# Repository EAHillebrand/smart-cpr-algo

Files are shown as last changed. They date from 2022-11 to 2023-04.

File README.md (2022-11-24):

# smart-cpr-algo
Model for smart CPR training mannequin

Developer Names: Anna, Anna, Eric, & Janek

Date of project start: Sept 8th, 2022

This project is a CPR training mannequin that provides live feedback to the learner. 

The folders and files for this project are as follows:
docs - Documentation for the project 
refs - Reference material used for the project, including papers 
src - Source code test - Test cases etc

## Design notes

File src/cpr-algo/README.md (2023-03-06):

# Simulink Model Details

Download cpr_vX.zip

Open and run the init_top_level.m
 -->Can choose the data loaded in init by which line is uncommented

Then open top_level_algo.slx (not .slxc)

Under simulation tab change run time to appropriate value

Then run from simulation tab

## Subsystem Notes

 ### Hardware Hiding:
 - Converts raw ADC value to distance in mm, uses low pass filter to limit bit switching

 ### Direction:
 - Determines the direction of distance (pos, zero, or neg)

 ### MinMax:
 - Identifies Local max and Min displaceent during compression

 ### Compression Detection:
 - Identifies a complete compression, counts number of compressions, records duration of compression in seconds

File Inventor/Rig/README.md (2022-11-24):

# Testing setup 

Used for collecting potentiometer data
Top level assembly is test

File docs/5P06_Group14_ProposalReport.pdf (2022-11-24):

### McMaster University

### IBEHS 5P06

# CPR Smart Mannequin Proposal Report

### October 21, 2022

Submitted by:

Group 14
Name | Email | Student ID
Anna Green | greena18@mcmaster.ca | 400117023
Anna Lopatukhin | lopatuka@mcmaster.ca | 400116519
Eric Hillebrand | hillebre@mcmaster.ca | 400143468
Janek Wolos | wolosj@mcmaster.ca | 400131936

### Table of Contents

Background Research | 3
Design Criteria | 5
Plan for Design Process | 6
Impact | 7
References | 8
Appendix A | 11
Appendix B | 12
Appendix C | 13
Anna Green | Eric Hillebrand
Anna Lopatukhin | Janek Wolos

### Background Research

CPR Overview: Cardiopulmonary resuscitation (CPR) is an emergency procedure administered during cardiac arrest wherein chest compressions are performed to replace the pumping of the heart and allow blood to keep flowing through the body. It is reported that about 9 in 10 people who experience cardiac arrest outside a hospital die [1]. If CPR is administered within the first few minutes of cardiac arrest, the chance of survival can double or triple [1]. There are various CPR certification courses available, but you do not require a certification or formal training to administer CPR [1]. There are two commonly known versions of CPR, conventional CPR, which uses chest compressions and mouth-to-mouth breathing, and compression-only CPR, which is simply conventional CPR without mouth-to-mouth breaths [2]. This background research focuses on adult CPR only. The Canadian Red Cross training services have outlined steps for administering conventional CPR to adults, shown in Figure 1A in Appendix A. The official CPR guidelines from the Heart and Stroke foundation outline that compressions must be at least 5 cm in depth with complete chest recoil, be performed at a rate of 100-120 compressions/min, have minimal interruptions, and that the compressor should use a 30:2 compression-ventilation ratio, and switch out with another compressor every 2 minutes [3]. The hands should be centered on the chest, with shoulders directly over the hands and elbows locked [4].

Smart CPR Mannequins: Smart CPR aids provide users with meaningful real-time feedback that improves CPR performance. The devices provide information to instructors so they can be effective teachers and precise evaluators. Smart training aids are available with a wide range of features. A number of smart mannequins were investigated and a summary table can be found in Table 1 of Appendix B. The features focus on relaying critical information, such as depth and rate of compressions, back to the user through audio and visual cues. The smart devices can relay the information to a central display to give instructors statistics and infographics on the class. The devices’ accurate, live feedback helps improve CPR training outcomes and retention [3]. An example of using smart mannequins was shown in a study where elderly participants learned how to perform CPR by watching a 30-min self-instructed video program while using an inflatable smart mannequin [5]. The CPR quality equaled a 4-hour professional class. After the training sessions, a smart mannequin was used to quantify the participants’ CPR proficiency [5]. In trained professionals, live feedback from smart mannequins during CPR training improved performance and received high ratings for usefulness and ease of use [6].

Regulations for CPR Mannequins: As the smart CPR mannequin is used for training, and not for treatment or health monitoring, it is not classified as a medical device and needs no regulatory approval process. Instead, the regulations are defined by various first-aid training bodies and foundations, most popular being the American Heart Association (AHA) and their 2020 Guidelines [7]. The guidelines contain several recommendations and standards for the design that should be met in a successful training device, including the types of feedback given and the evaluation methods. While it is up to individual foundations to decide whether they want to use a particular mannequin for training, most base their decision on meeting the AHA Guidelines [8].

Anna Green | Eric Hillebrand

Patents
Patents of current designs were studied to better understand our market environment. The solutions found can be broken down into three main areas: regular mannequins, smart mannequins, and CPR feedback devices.

Regular Mannequins: These patents provide descriptions of the mechanical design and feedback system, such as spring design, simulating chest compressions and airways, and the mannequin anatomical structure [9], [10], [11]. They provide information on durability, portability, and manufacturing solutions [9], [10], [11]. One of the patents uses a fluid to provide a damping effect, stepping away from the linear spring method used in other cases, which research has shown to be more accurate of a real chest during compression [9].

Smart Mannequins: In addition to the mechanical design trying to mimic a realistic torso, this patent contains a sensor housing fitted with a force sensor and an acceleration sensor [12]. The patent goes in-depth about the types and layout of the sensors, explaining the idea behind having separate sensors working together as a fail-proof mechanism [12].

CPR Feedback Devices: These patents are for monitoring devices that use sensors to provide feedback on the quality of the CPR given during an emergency [13], [14]. One relies on pressure pads on the chest and back of the patient and uses the difference in the amplitudes and frequency collected to calculate compression and rate [14]. The second device uses an ultrasonic wave transmitter on the chest and a receiver on the back of the victim. The time of flight between the transmitter and receiver is used to calculate compression depth and the frequency [13]. As these are to be used on humans, it is less applicable to our training use case, however we could take inspiration from the solutions for the sensor setup and type of data collected.

### Problem Statement and Needs Identification

Problem Statement: Lack of effective CPR education of laypersons in developing countries is currently hindering the administration of lifesaving treatment for out-of-hospital cardiac arrests (OHCA), which occurs with an annual incidence of 350,000 in the United States alone and has a mortality rate of approximately 90% [15]. A method to effectively and easily teach CPR to laypersons of various backgrounds and education is needed, ensuring that trainees can perform quality CPR in an emergency and retain the information and skill set for sufficient time.

Client Needs: The client requires a means of delivering effective CPR training to laypersons in developing countries. The client has allowed for an open-ended method of accomplishing this goal, giving examples such as a smart CPR mannequin, or a CPR training program. Although the client seemed more focused on a smart CPR mannequin, we intend to quell this bias as much as possible in our brainstorming process, as the problem statement outlines only that a CPR training solution be implemented. CPR training relies on providing the learner with the necessary information and skillset, and ensuring retention of the skill to later perform in an emergency setting. This requires professional instruction and repetition of good technique on a realistic subject. No matter the physical manifestation of the solution, it must be able to measure and give real time feedback to both the student and the instructor pertaining to the quality of chest compressions. Quality of chest compressions is broken down into quality of compression rate,
Anna Green | Eric Hillebrand

depth, recoil, chest compression fraction, and hand position. The client has specified that ventilation is not a requirement for the CPR training they wish to give. Further research to justify this choice shows that compression-only CPR is easier for a layperson to perform, and that it results in similar survival rates for adult cardiac arrests of cardiac etiology compared to CPR with rescue breaths [16]. The client also requires that the quality-of-compression data be available to provide remote certification of CPR competence. The structure of CPR lessons is assumed to remain consistent with instruction followed by practicing the skill and receiving feedback. The client specified that electronic components need to have a shelf life greater than 2 years, so that the battery and components must last through regular use and possible charging. The aid must also be convenient to transport overseas, and must use universal conventions to be easily used in different countries.

Uncertainties and Challenges: The lack of robust and routine data collection surrounding OHCA in developing countries makes it difficult to put the problem statement and client needs into quantitative terms. The motivation behind this project was derived from lived experience and probabilistic evidence sourced by the client related to CPR training in developing countries. While there are studies that focus on OHCA in developing countries, those studies are, again, founded on limited statistical evidence. Furthermore, the client has listed many countries in which they have connections for a CPR training program to be started, but they have not decided which specific country they would like to target. This might present some issues when assessing feasibility of solutions in different countries, and designing for specific languages and cultures of learning. This could mean that we create our own scope and choose a specific country to target ourselves.

### Design Criteria

The following design criteria are guided by minimum features of adult CPR mannequins established by the American Red Cross First Aid CPR certification courses and professional guidelines for performing CPR from the Heart and Stroke foundation [3].

Affordability: In discussions with stakeholders involved in CPR training programs, it was identified that having a low cost product is of significant importance. The product should be more affordable compared to current existing models and ideally, be easily purchased in developing countries. This will be quantifiable, with a goal to achieve a cost less than $172, which is the price for a basic feedback-capable mannequin available for sale [17].

Portability: The product should be easily portable. Devices that are too large become difficult to transport (especially overseas) and may discourage users from purchasing the product. This will be quantifiable, with a goal to have a design less than 7lbs, which is the weight for a standard CPR mannequin [18]. The device should be usable without electrical connection during use, be easily charged and/or require batteries that are universally accessible.

Safety: The device must have minimal safety risk. This means the integrity of all mechanical and electrical components is confirmed. At a minimum, the design will be as safe as current products on the market. The device should not include materials such as latex, which may cause allergic reactions in some users.

Anna Green | Eric Hillebrand

Accessibility: Operation should be easily understood regardless of prior knowledge, experience, or language(s) spoken. The product should incorporate as many non-linguistic cues as possible, such as lights, sounds, vibrations, etc., which can be adjusted to fit the needs of the user. If linguistic cues are needed, it should aim to be able to accommodate different languages.

Durability: The product should be made of materials that increase longevity and sustainability of the device, and be able to withstand a minimum of 125 uses [19]. The material should be minimally absorbent and easily disinfected, to mitigate the transfer of communicable diseases [19]. The instructions for decontamination must be simple and distributed with the product.

Feedback System: The feedback system should incorporate real-time simulated audio, visual or sensory cues which respond accurately to the depth, compression rate, and fraction. The feedback must accurately follow professional guidelines established by the Heart and Stroke foundation [3]. These guidelines identify a minimum depth of 5 cm, a compression rate of 100-120/ min, complete chest recoil, and minimal interruptions in compressions [3]. A successful feedback system will identify when the user is matching guidelines, nearing the guidelines, or failing to meet the guidelines. The feedback system may ideally notify the user when compression has exceeded 2 minutes, as it is recommended the CPR provider is changed every 2 minutes [3].

Ease of Manufacturing: A desirable design should be easily manufacturable. This will likely reduce the cost and make maintenance/repairs more accessible. Easily manufacturable designs will be identified by their use of standard parts, easily replaceable components, and the use of standard practices in manufacturing.

Sensor and Measurements: The sensor system of the design should collect reliable, robust and consistent data as it will be used downstream in providing the feedback to the trainee. As the measurements will be used as the foundation for the rest of the system, the data flow needs to be consistent under all conditions and pass a variety of stringent hazard analyses.

Design Criteria Challenges
The main challenges that will have to be addressed for this design will revolve around finding a good middle ground amongst the criteria defined above. When taken to the extremes, some of the design requirements are conflicting to one another, for example, extremely high quality sensors will not be the most affordable. Finding the optimal point to maximize each of them will be a significant obstacle, and will take planning and several iterations to get right.

### Plan for Design Process

The project plan, deliverables, and detailed timeline is found in the Gantt Chart in Appendix C.

Semester 1: The team will participate in background research, design process planning, and problem identification and analysis. In October/November, members will generate initial design ideas and then select a final design after a design review. In early December, the team will order the required parts and/or begin fabrication of components.

Anna Green | Eric Hillebrand

Semester 2: The team will build, test, and refine the device. In January, the team will build the first prototype. In early February, testing will begin. In late February, a second prototype will be built with further testing. The rest of the term will be overflow in case challenges arise.

Potential Challenges: To build in semester 2, the preliminary design must be completed by mid-December to allow time for parts procurement and fabrication. If the majority of parts are to be fabricated, fabrication may be pushed to mid/late January. However, parts identification will start in mid November, so if it is identified that the majority of parts need to be fabricated, the Mechanical Sub-Team will adjust the schedule accordingly.

Fabrication Planning and Budget Considerations: All members will keep in mind the budget of $1000. All members will receive second-floor machine shop and hatch bay training for fabrication purposes.

### Impact

Even in the U.S., the mortality rate from OHCA is still 90% on some 350,000 events each year. In developing countries, the belief that CPR can only be performed by medical professionals in hospitals is strongly held. It is evident that effective layperson CPR training would have a great benefit to unlearning this belief and saving lives around the world. In a scoping review performed by Thibodeau et al. pertaining to OHCA in Africa, several papers identified cardiovascular disease (CVD) as an underlying cause of OHCA, and discussed how the incidence of CVD is expected to double in Africa [20]. We can proactively prepare the public to deal with this impending increase in OHCA through the implementation of CPR training. The development of a feedback-based CPR training tool in this project will have a strong impact in this respect, as shown by studies that discuss the benefits of CPR training with feedback, compared to no feedback. One study found that people trained with just one minute of real-time visual feedback scored 10.8% higher than the people with no feedback in overall CPR score (which accounted for compression depth and rate, chest recoil, hand position) [21]. Another study had one group of participants watching an instructional video while practicing CPR on a mannequin, and another group receiving real-time computer-voice feedback on the quality of their CPR. The non-feedback group only improved from 5% to 8% of participants successfully meeting all the CPR criteria, whereas the feedback group improved from 4% to 19% [22]. Not only will this project have an impact on people requiring life support from witnesses to OHCA, but it will also impact CPR instructors. The American Heart Association discusses the difficulty of detecting inadequate CPR performance in traditional instruction practices, which makes it challenging to fine tune the feedback they give. They believe that implementing a more technologically advanced, feedback-based CPR training solution would help tackle this problem [23].

Anna Green | Eric Hillebrand

### References

[1] “Three things you may not know about CPR,” Centers for Disease Control and Prevention, 22-Oct-2021. [Online]. Available: https://www.cdc.gov/heartdisease/cpr.htm. [Accessed: 20-Oct-2022].
[2] “What is CPR,” cpr.heart.org. [Online]. Available: https://cpr.heart.org/en/resources/what-is-cpr. [Accessed: 20-Oct-2022].
[3] “2020 Guidelines for CPR & ECC,” Heart & stroke training portal. [Online]. Available: https://cpr.heartandstroke.ca/s/article/2020-Guidelines?language=en_US. [Accessed: 20-Oct-2022].
[4] “CPR steps: Perform CPR,” Red Cross. [Online]. Available: https://www.redcross.org/take-a-class/cpr/performing-cpr/cpr-steps. [Accessed: 20-Oct-2022].
[5] B. Lynch, E. L. Einspruch, G. Nichol, L. B. Becker, T. P. Aufderheide, and A. Idris, “Effectiveness of a 30-min CPR self-instruction program for Lay Responders: A controlled randomized study,” Resuscitation, vol. 67, no. 1, pp. 31–43, Oct. 2005.
[6] J. R. Smart, K. Kranz, F. Carmona, T. W. Lindner, and A. Newton, “Does real-time objective feedback and competition improve performance and quality in manikin CPR training – a prospective observational study from several European EMS,” Scandinavian Journal of Trauma, Resuscitation and Emergency Medicine, vol. 23, no. 1, 2015.
[7] A. Cheng, D. J. Magid, M. Auerbach, F. Bhanji, B. L. Bigham, A. L. Blewer, K. N. Dainty, E. Diederich, Y. Lin, M. Leary, M. Mahgoub, M. E. Mancini, K. Navarro, and A. Donoghue, “Part 6: Resuscitation education science: 2020 American Heart Association guidelines for Cardiopulmonary Resuscitation and emergency cardiovascular care,” Circulation, vol. 142, no. 16_suppl_2, 2020.
[8] “Use of Feedback Devices in Resuscitation Training Courses Policy,” Heart & stroke training portal. [Online]. Available: https://cpr.heartandstroke.ca/s/article/Use-of-Feedback-Devices-in-Resuscitation-Training-Courses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. [Accessed: 20-Oct-2022].
[9] J. Nysaether and I. Rafoss, “Chest simulator,” US20070264621A1, 15-Nov-2007.
[10] R. Brault, D. Croteau, and J. Vinden, “CPR manikin,” US4984987A, 15-Jan-1991.
[11] J. Lehman, “Training manikan,” US5628633A, 13-May-1997.
Anna Green | Eric Hillebrand

[12] Y. Kwon, S. Park, S. Lee, H. Lee, “Cpr training system and method,” EP3440659B1, 1-December-2021
[13] P. Peterson, K. Olson, “CPR feedback method and apparatus,” US8600522B2, 3-December- 2013
[14] C. Centen, S. Smith, G. Browne, R. Lee, M. Wilkinson, R. Nova, “Reference sensor for cpr feedback device,” US20120083720A1, 8-Novemeber-2016
[15] “CPR Facts and stats,” cpr.heart.org. [Online]. Available: https://cpr.heart.org/en/resources/cpr-facts-and-stats. [Accessed: 20-Oct-2022].
[16] “Highlights - heart and stroke foundation of Canada,” American Heart Association. [Online]. Available:
https://www.heartandstroke.ca/-/media/pdf-files/canada/cpr-2017/ecc-highlights-of-2015-guidelines-update-for-cpr-ecclr.ashx. [Accessed: 21-Oct-2022].
[17] EMS Safety United States. [Online]. Available: https://store.osmanager4.com/emss/groups/459/1230. [Accessed: 20-Oct-2022].
[18] “Covid 19 essentials,” CPR Savers & First Aid Supply. [Online]. Available: https://cpr-savers.com/CPR-Manikin-Comparison-Chart_ep_63-1.html. [Accessed: 20-Oct-2022].
[19] “American Red Cross training manikin requirements - CPR savers.” [Online]. Available: https://cpr-savers.com/assets/images/pdf/american-red-cross-training-manikin-requireme nts.pdf. [Accessed: 20-Oct-2022].
[20] J. Thibodeau, K. Werner, L. A. Wallis, and W. Stassen, “Out-of-hospital cardiac arrest in Africa: A scoping review,” BMJ Open, vol. 12, no. 3, 2022.
[21] E. Baldi, S. Cornara, E. Contri, F. Epis, D. Fina, B. Zelaschi, C. Dossena, F. Fichtner, M. Tonani, M. Di Maggio, E. Zambaiti, and A. Somaschini, “Real-time visual feedback during training improves laypersons’ CPR quality: a randomized controlled manikin study,” CJEM, vol. 19, no. 6, pp. 480–487, 2017.
[22] N. Mpotos, L. Yde, P. Calle, E. Deschepper, M. Valcke, W. Peersman, L. Herregods, and K. Monsieurs, “Retraining basic life support skills using video, voice feedback or both: A randomised controlled trial,” Resuscitation, vol. 84, no. 1, pp. 72–77, 2013.
[23] “American Heart Association (AHA) requirement on use of feedback devices ...” [Online].
Anna Green | Eric Hillebrand

Available:https://ahainstructornetwork.americanheart.org/idc/groups/ahaecc-public/@wcm/@ecc/documents/downloadable/ucm_495639.pdf. [Accessed: 20-Oct-2022].

[24] “3 4 - Canadian Red Cross.” [Online]. Available: https://www.redcross.ca/crc/documents/fa_poster_cpr_web.pdf. [Accessed: 20-Oct-2022].
[25] “Professional adult series 2000 manikin,” PRESTAN Products. [Online]. Available: https://www.prestanproducts.com/products/cpr-training-manikins/professional-adult-series-2000-manikin/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. [Accessed: 20-Oct-2022].
[26] SmartMan, “World's best resuscitation practice,” SmartMan Emergency Resuscitation Simulation Systems. [Online]. Available: http://smartman.biz/. [Accessed: 20-Oct-2022].
[27] “Little Anne QCPR - creating Quality Lifesavers,” Laerdal Medical. [Online]. Available: https://laerdal.com/ca/products/simulation-training/resuscitation-training/little-anne-qcpr. [Accessed: 20-Oct-2022].
[28] “HAL® S315 adult airway and CPR trainer with OMNI® 2,” Gaumard Scientific. [Online]. Available: https://www.gaumard.com/s315-omni2. [Accessed: 20-Oct-2022].
Anna Green | Eric Hillebrand

### Appendix A

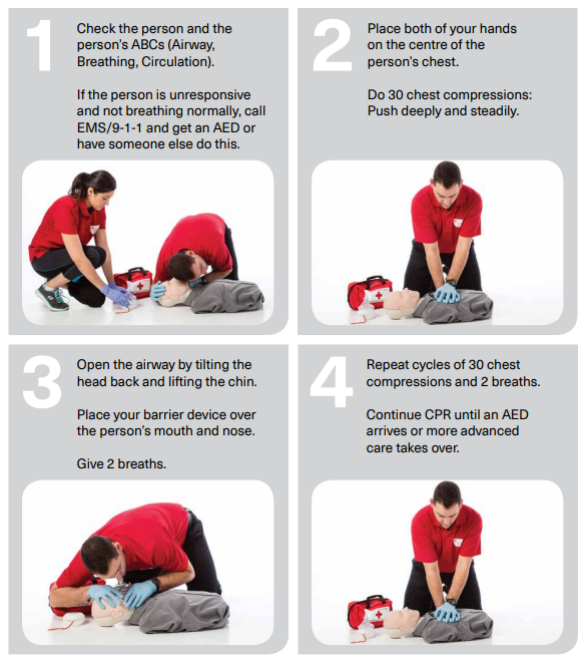
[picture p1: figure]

Figure 1A: Canadian Red Cross Conventional CPR Steps for an Adult [24]

Anna Green | Eric Hillebrand

### Appendix B

Table 1: Current Smart Mannequins on the Market and Key Features
Product Name | Company | Description | Key Features | Cost (CAD)
Professional Adult Series 2000 Manikin [25] | Prestan | Realistic adult mannequin with advanced real-time feedback Fully compliant with industry guidelines Available in different skin tones | Compression rate Depth Recoil Ventilation Hands-off time Bluetooth connection Mobile app LED feedback | 302.28
BLS CPR Pro – SM201 [26] | SmartMan | Adjustable-Real chest resistance Monitors performance and detects Mistakes | Real-time feedback Metronome External screen Compression modes | Not Available
Little Anne QCPR [27] | Laerdal | Quality CPR (QCPR) feedback technology Help instructors improve CPR training quality, classroom efficiency and learner engagement. | Real-time feedback Race competition Scoring Guidance | 310
HAL® S315 Adult Airway and CPR Trainer with OMNI® 2 [28] | Gaumard | A CPR trainer designed for teaching resuscitation skills Realistic chest cavity resistance and recoil Performance report providing averages for CPR metrics | Real-time feedback Compression depth Rate Ventilation rate Excessive ventilation Metronome Resuscitation algorithm Checklists | 2135
Anna Green | Eric Hillebrand

### Appendix C

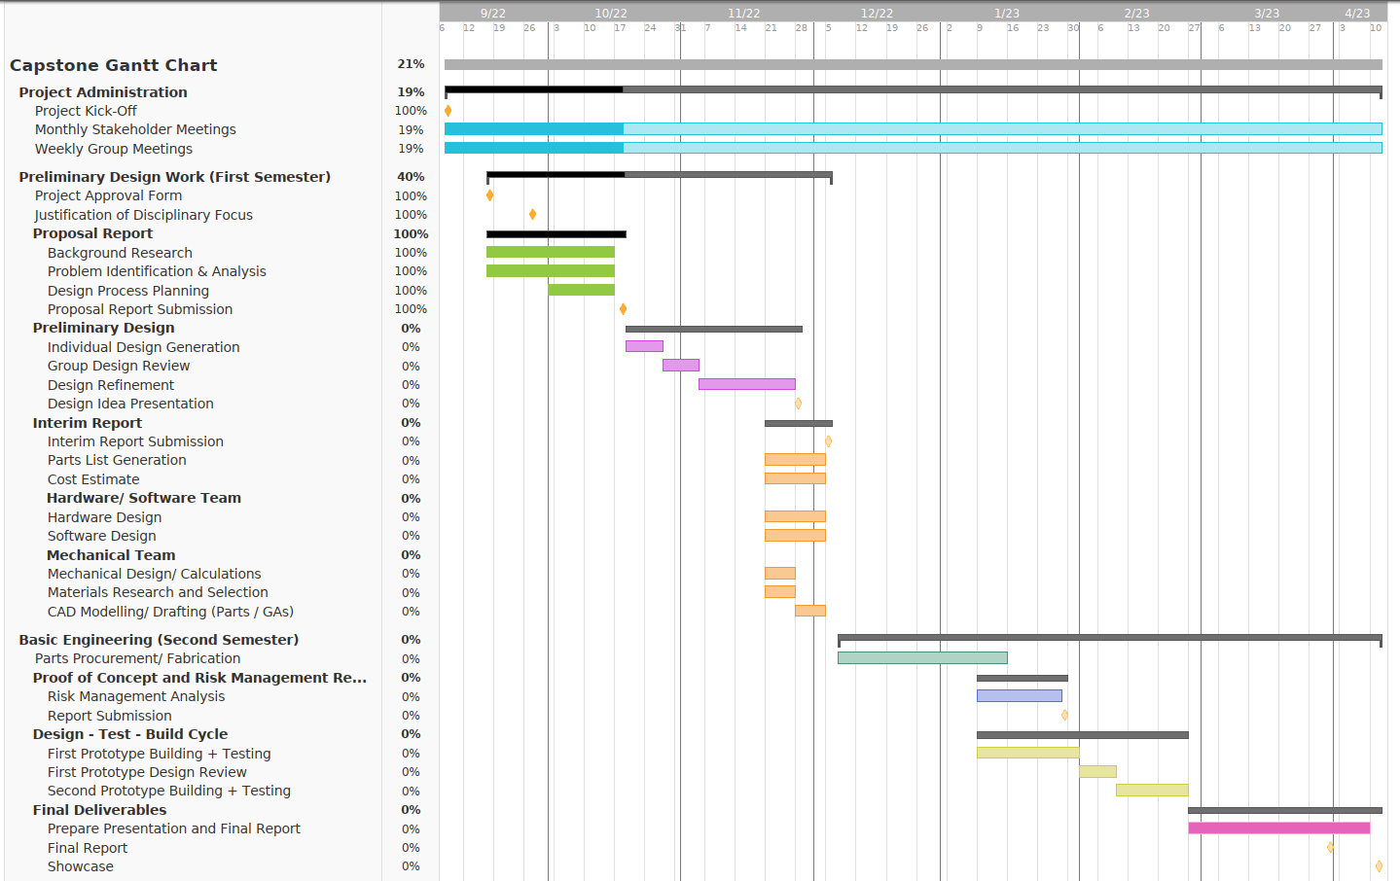
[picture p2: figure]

Figure 1C: Gantt Chart
Anna Green | Eric Hillebrand
Anna Lopatukhin | Janek Wolos

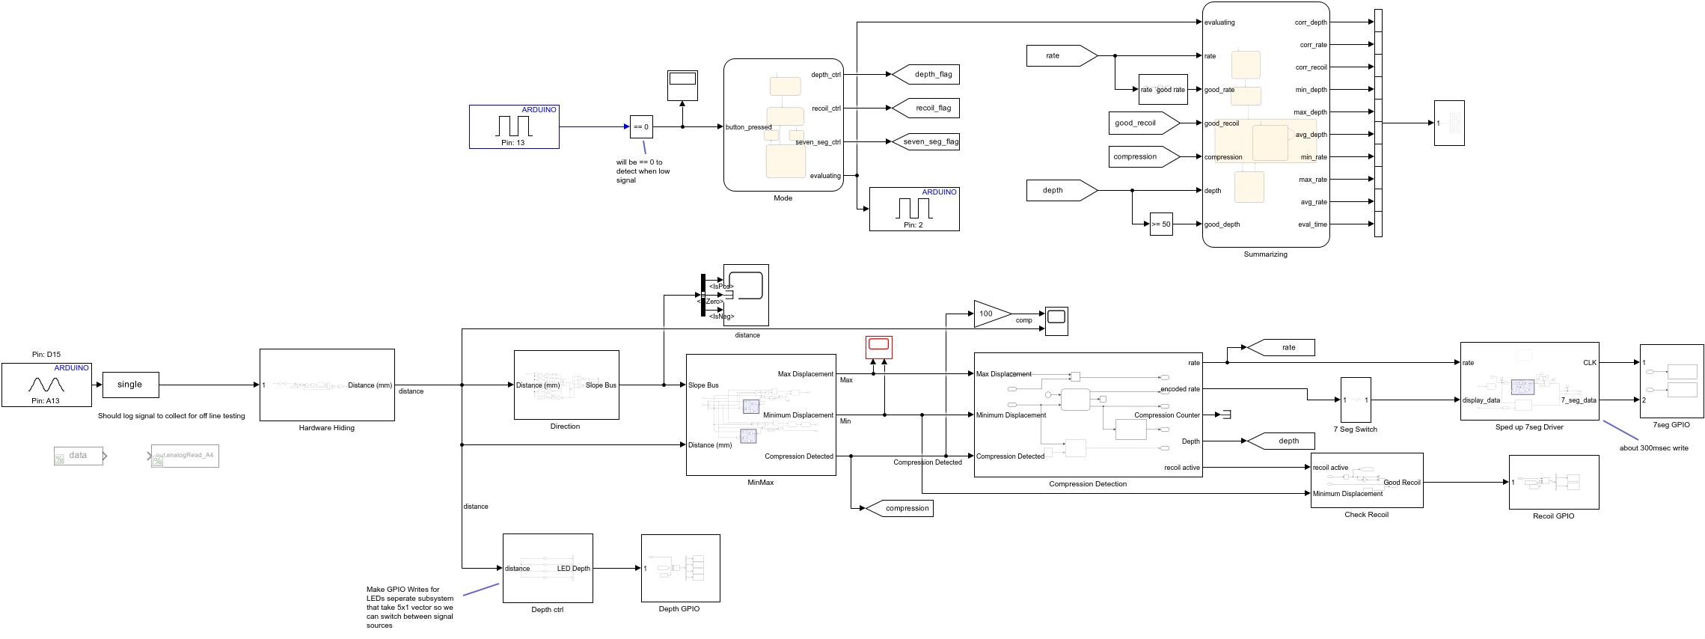
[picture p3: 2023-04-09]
src/cpr-algo/model.jpeg

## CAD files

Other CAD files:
Inventor/Rig/3D_model_PN_3540s-1-503l.ipt
Inventor/Rig/base.ipt
Inventor/Rig/bushing_loose.ipt
Inventor/Rig/bushing_tight.ipt
Inventor/Rig/gear_trial1.iam
Inventor/Rig/pinion.ipt
Inventor/Rig/pinion_gear.ipt
Inventor/Rig/pinion_gear_loose.ipt
Inventor/Rig/pinion_gear_mid.ipt
Inventor/Rig/pinion_gear_tight.ipt
Inventor/Rig/pot_stand.ipt
Inventor/Rig/push_plate.ipt
Inventor/Rig/rack.ipt
Inventor/Rig/rack_tooth.ipt
Inventor/Rig/rod.ipt
Inventor/Rig/test.iam

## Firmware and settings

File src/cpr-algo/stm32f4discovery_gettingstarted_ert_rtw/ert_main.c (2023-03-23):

/*
 * Academic License - for use in teaching, academic research, and meeting
 * course requirements at degree granting institutions only.  Not for
 * government, commercial, or other organizational use.
 *
 * File: ert_main.c
 *
 * Code generated for Simulink model 'stm32f4discovery_gettingstarted'.
 *
 * Model version                  : 12.0
 * Simulink Coder version         : 9.8 (R2022b) 13-May-2022
 * C/C++ source code generated on : Sat Mar 18 09:36:49 2023
 *
 * Target selection: ert.tlc
 * Embedded hardware selection: ARM Compatible->ARM Cortex
 * Code generation objectives: Unspecified
 * Validation result: Not run
 */

#include "stm32f4discovery_gettingstarted.h"
#include "rtwtypes.h"
#include "MW_target_hardware_resources.h"

volatile int IsrOverrun = 0;
static boolean_T OverrunFlag = 0;
void rt_OneStep(void)
{
  /* Check for overrun. Protect OverrunFlag against preemption */
  if (OverrunFlag++) {
    IsrOverrun = 1;
    OverrunFlag--;
    return;
  }

  __enable_irq();
  stm32f4discovery_gettingstarted_step();

  /* Get model outputs here */
  __disable_irq();
  OverrunFlag--;
}

volatile boolean_T stopRequested;
volatile boolean_T runModel;
int main(int argc, char **argv)
{
  float modelBaseRate = 0.1;
  float systemClock = 168.0;

  /* Initialize variables */
  stopRequested = false;
  runModel = false;

#if !defined(MW_FREERTOS) && defined(MW_MULTI_TASKING_MODE) && (MW_MULTI_TASKING_MODE == 1)

  MW_ASM (" SVC #1");

#endif

  ;

  // Peripheral initialization imported from STM32CubeMX project;
  HAL_Init();
  SystemClock_Config();
  PeriphCommonClock_Config();
  MX_GPIO_Init();
  MX_DMA_Init();
  MX_I2C3_Init();
  MX_SPI5_Init();
  MX_TIM1_Init();
  MX_USART1_UART_Init();
  MX_ADC3_Init();
  rtmSetErrorStatus(stm32f4discovery_gettingstar_M, 0);
  stm32f4discovery_gettingstarted_initialize();
  __disable_irq();
  ARMCM_SysTick_Config(modelBaseRate);
  runModel = rtmGetErrorStatus(stm32f4discovery_gettingstar_M) == (NULL);
  __enable_irq();
  __enable_irq();
  while (runModel) {
    stopRequested = !(rtmGetErrorStatus(stm32f4discovery_gettingstar_M) == (NULL));
    if (stopRequested) {
      SysTick->CTRL &= ~SysTick_CTRL_ENABLE_Msk;
    }

    ;
  }

  /* Terminate model */
  stm32f4discovery_gettingstarted_terminate();

#if !defined(MW_FREERTOS) && !defined(USE_RTX)

  (void) systemClock;

#endif

  ;
  __disable_irq();
  return 0;
}

/*
 * File trailer for generated code.
 *
 * [EOF]
 */

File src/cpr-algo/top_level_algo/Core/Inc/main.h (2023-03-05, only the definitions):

#define PC14_OSC32_IN_Pin LL_GPIO_PIN_14
#define PC14_OSC32_IN_GPIO_Port GPIOC
#define PC15_OSC32_OUT_Pin LL_GPIO_PIN_15
#define PC15_OSC32_OUT_GPIO_Port GPIOC
#define A0_Pin LL_GPIO_PIN_0
#define A0_GPIO_Port GPIOF
#define A1_Pin LL_GPIO_PIN_1
#define A1_GPIO_Port GPIOF
#define A2_Pin LL_GPIO_PIN_2
#define A2_GPIO_Port GPIOF
#define A3_Pin LL_GPIO_PIN_3
#define A3_GPIO_Port GPIOF
#define A4_Pin LL_GPIO_PIN_4
#define A4_GPIO_Port GPIOF
#define SPI5_SCK_Pin LL_GPIO_PIN_7
#define SPI5_SCK_GPIO_Port GPIOF
#define SPI5_MISO_Pin LL_GPIO_PIN_8
#define SPI5_MISO_GPIO_Port GPIOF
#define SPI5_MOSI_Pin LL_GPIO_PIN_9
#define SPI5_MOSI_GPIO_Port GPIOF
#define ENABLE_Pin LL_GPIO_PIN_10
#define ENABLE_GPIO_Port GPIOF
#define PH0_OSC_IN_Pin LL_GPIO_PIN_0
#define PH0_OSC_IN_GPIO_Port GPIOH
#define PH1_OSC_OUT_Pin LL_GPIO_PIN_1
#define PH1_OSC_OUT_GPIO_Port GPIOH
#define SDNWE_Pin LL_GPIO_PIN_0
#define SDNWE_GPIO_Port GPIOC
#define NCS_MEMS_SPI_Pin LL_GPIO_PIN_1
#define NCS_MEMS_SPI_GPIO_Port GPIOC
#define CSX_Pin LL_GPIO_PIN_2
#define CSX_GPIO_Port GPIOC
#define B1_Pin LL_GPIO_PIN_0
#define B1_GPIO_Port GPIOA
#define MEMS_INT1_Pin LL_GPIO_PIN_1
#define MEMS_INT1_GPIO_Port GPIOA
#define MEMS_INT2_Pin LL_GPIO_PIN_2
#define MEMS_INT2_GPIO_Port GPIOA
#define B5_Pin LL_GPIO_PIN_3
#define B5_GPIO_Port GPIOA
#define VSYNC_Pin LL_GPIO_PIN_4
#define VSYNC_GPIO_Port GPIOA
#define G2_Pin LL_GPIO_PIN_6
#define G2_GPIO_Port GPIOA
#define ACP_RST_Pin LL_GPIO_PIN_7
#define ACP_RST_GPIO_Port GPIOA
#define OTG_FS_PSO_Pin LL_GPIO_PIN_4
#define OTG_FS_PSO_GPIO_Port GPIOC
#define OTG_FS_OC_Pin LL_GPIO_PIN_5
#define OTG_FS_OC_GPIO_Port GPIOC
#define R3_Pin LL_GPIO_PIN_0
#define R3_GPIO_Port GPIOB
#define R6_Pin LL_GPIO_PIN_1
#define R6_GPIO_Port GPIOB
#define BOOT1_Pin LL_GPIO_PIN_2
#define BOOT1_GPIO_Port GPIOB
#define SDNRAS_Pin LL_GPIO_PIN_11
#define SDNRAS_GPIO_Port GPIOF
#define A6_Pin LL_GPIO_PIN_12
#define A6_GPIO_Port GPIOF
#define A7_Pin LL_GPIO_PIN_13
#define A7_GPIO_Port GPIOF
#define A8_Pin LL_GPIO_PIN_14
#define A8_GPIO_Port GPIOF
#define A9_Pin LL_GPIO_PIN_15
#define A9_GPIO_Port GPIOF
#define A10_Pin LL_GPIO_PIN_0
#define A10_GPIO_Port GPIOG
#define A11_Pin LL_GPIO_PIN_1
#define A11_GPIO_Port GPIOG
#define D4_Pin LL_GPIO_PIN_7
#define D4_GPIO_Port GPIOE
#define D7_Pin LL_GPIO_PIN_10
#define D7_GPIO_Port GPIOE
#define D8_Pin LL_GPIO_PIN_11
#define D8_GPIO_Port GPIOE
#define D9_Pin LL_GPIO_PIN_12
#define D9_GPIO_Port GPIOE
#define D10_Pin LL_GPIO_PIN_13
#define D10_GPIO_Port GPIOE
#define D11_Pin LL_GPIO_PIN_14
#define D11_GPIO_Port GPIOE
#define D12_Pin LL_GPIO_PIN_15
#define D12_GPIO_Port GPIOE
#define G4_Pin LL_GPIO_PIN_10
#define G4_GPIO_Port GPIOB
#define G5_Pin LL_GPIO_PIN_11
#define G5_GPIO_Port GPIOB
#define OTG_HS_ID_Pin LL_GPIO_PIN_12
#define OTG_HS_ID_GPIO_Port GPIOB
#define VBUS_HS_Pin LL_GPIO_PIN_13
#define VBUS_HS_GPIO_Port GPIOB
#define OTG_HS_DM_Pin LL_GPIO_PIN_14
#define OTG_HS_DM_GPIO_Port GPIOB
#define OTG_HS_DP_Pin LL_GPIO_PIN_15
#define OTG_HS_DP_GPIO_Port GPIOB
#define TE_Pin LL_GPIO_PIN_11
#define TE_GPIO_Port GPIOD
#define RDX_Pin LL_GPIO_PIN_12
#define RDX_GPIO_Port GPIOD
#define WRX_DCX_Pin LL_GPIO_PIN_13
#define WRX_DCX_GPIO_Port GPIOD
#define D0_Pin LL_GPIO_PIN_14
#define D0_GPIO_Port GPIOD
#define D1_Pin LL_GPIO_PIN_15
#define D1_GPIO_Port GPIOD
#define BA0_Pin LL_GPIO_PIN_4
#define BA0_GPIO_Port GPIOG
#define BA1_Pin LL_GPIO_PIN_5
#define BA1_GPIO_Port GPIOG
#define R7_Pin LL_GPIO_PIN_6
#define R7_GPIO_Port GPIOG
#define DOTCLK_Pin LL_GPIO_PIN_7
#define DOTCLK_GPIO_Port GPIOG
#define SDCLK_Pin LL_GPIO_PIN_8
#define SDCLK_GPIO_Port GPIOG
#define HSYNC_Pin LL_GPIO_PIN_6
#define HSYNC_GPIO_Port GPIOC
#define G6_Pin LL_GPIO_PIN_7
#define G6_GPIO_Port GPIOC
#define I2C3_SDA_Pin LL_GPIO_PIN_9
#define I2C3_SDA_GPIO_Port GPIOC
#define I2C3_SCL_Pin LL_GPIO_PIN_8
#define I2C3_SCL_GPIO_Port GPIOA
#define STLINK_RX_Pin LL_GPIO_PIN_9
#define STLINK_RX_GPIO_Port GPIOA
#define STLINK_TX_Pin LL_GPIO_PIN_10
#define STLINK_TX_GPIO_Port GPIOA
#define R4_Pin LL_GPIO_PIN_11
#define R4_GPIO_Port GPIOA
#define R5_Pin LL_GPIO_PIN_12
#define R5_GPIO_Port GPIOA
#define SWDIO_Pin LL_GPIO_PIN_13
#define SWDIO_GPIO_Port GPIOA
#define SWCLK_Pin LL_GPIO_PIN_14
#define SWCLK_GPIO_Port GPIOA
#define TP_INT1_Pin LL_GPIO_PIN_15
#define TP_INT1_GPIO_Port GPIOA
#define R2_Pin LL_GPIO_PIN_10
#define R2_GPIO_Port GPIOC
#define D2_Pin LL_GPIO_PIN_0
#define D2_GPIO_Port GPIOD
#define D3_Pin LL_GPIO_PIN_1
#define D3_GPIO_Port GPIOD
#define G7_Pin LL_GPIO_PIN_3
#define G7_GPIO_Port GPIOD
#define B2_Pin LL_GPIO_PIN_6
#define B2_GPIO_Port GPIOD
#define G3_Pin LL_GPIO_PIN_10
#define G3_GPIO_Port GPIOG
#define B3_Pin LL_GPIO_PIN_11
#define B3_GPIO_Port GPIOG
#define B4_Pin LL_GPIO_PIN_12
#define B4_GPIO_Port GPIOG
#define LD4_Pin LL_GPIO_PIN_14
#define LD4_GPIO_Port GPIOG
#define SDNCAS_Pin LL_GPIO_PIN_15
#define SDNCAS_GPIO_Port GPIOG
#define SDCKE1_Pin LL_GPIO_PIN_5
#define SDCKE1_GPIO_Port GPIOB
#define SDNE1_Pin LL_GPIO_PIN_6
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

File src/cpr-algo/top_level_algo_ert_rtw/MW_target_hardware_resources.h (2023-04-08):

#ifndef PORTABLE_WORDSIZES
#ifdef __MW_TARGET_USE_HARDWARE_RESOURCES_H__
#ifndef __MW_TARGET_HARDWARE_RESOURCES_H__
#define __MW_TARGET_HARDWARE_RESOURCES_H__

#define MW_MULTI_TASKING_MODE 1
#include "MW_ArduinoHWInit.h"

#define MW_USECODERTARGET 1
#define MW_TARGETHARDWARE ESP32-WROOM(Arduino Compatible)
#define MW_EXTMODEPROTOCOLINFO_XCPONSERIAL_HOSTINTERFACE Simulink
#define MW_EXTMODEPROTOCOLINFO_XCPONSERIAL_LOGGINGBUFFERAUTO 1
#define MW_EXTMODEPROTOCOLINFO_XCPONSERIAL_LOGGINGBUFFERSIZE 250
#define MW_EXTMODEPROTOCOLINFO_XCPONSERIAL_LOGGINGBUFFERNUM 3
#define MW_EXTMODEPROTOCOLINFO_XCPONSERIAL_MAXCONTIGSAMPLES 10
#define MW_EXTMODEPROTOCOLINFO_XCPONWIFI_HOSTINTERFACE Simulink
#define MW_EXTMODEPROTOCOLINFO_XCPONWIFI_LOGGINGBUFFERAUTO 1
#define MW_EXTMODEPROTOCOLINFO_XCPONWIFI_LOGGINGBUFFERSIZE 250
#define MW_EXTMODEPROTOCOLINFO_XCPONWIFI_LOGGINGBUFFERNUM 3
#define MW_EXTMODEPROTOCOLINFO_XCPONWIFI_MAXCONTIGSAMPLES 10
#define MW_CONNECTIONINFO_XCPONSERIAL_BAUDRATE codertarget.arduinobase.registry.getBaudRate
#define MW_CONNECTIONINFO_XCPONSERIAL_COMPORT codertarget.arduinobase.internal.getExternalModeMexArgs('Serial')
#define MW_CONNECTIONINFO_XCPONSERIAL_VERBOSE 0
#define MW_CONNECTIONINFO_XCPONWIFI_IPADDRESS codertarget.arduinobase.internal.getExternalModeMexArgs('Wifi')
#define MW_CONNECTIONINFO_XCPONWIFI_PORT 17725
#define MW_CONNECTIONINFO_XCPONWIFI_VERBOSE 0
#define MW_EXTMODE_CONFIGURATION XCP on Serial
#define MW_EXTMODE_COMPORTBAUD 921600
#define MW_RTOS FreeRTOS
#define MW_RTOSBASERATETASKPRIORITY 14
#define MW_DETECTTASKOVERRUNS 0.000000
#define MW_SCHEDULER_INTERRUPT_SOURCE 0
#define MW_ESP32_ESP32_BOARD -1
#define MW_RUNTIME_BUILDACTION 1
#define MW_RUNTIME_DISABLEPARALLELBUILD 0
#define MW_RUNTIME_FORCEBUILDSTATICLIBRARY 0
#define MW_HOSTBOARDCONNECTION_APPDOWNLOAD_PORT_SOURCE 1
#define MW_HOSTBOARDCONNECTION_APPDOWNLOAD_COMPORT_SELECT -1
#define MW_HOSTBOARDCONNECTION_APPDOWNLOAD_COMPORT_SPECIFY 1
#define MW_HOSTBOARDCONNECTION_APPDOWNLOAD_BAUD 0
#define MW_HOSTBOARDCONNECTION_APPDOWNLOAD_BAUD_SPECIFY 
#define MW_HOSTBOARDCONNECTION_CONNECTEDIO_SERIAL_PORT 0
#define MW_HOSTBOARDCONNECTION_CONNECTEDIO_PORT_SOURCE1 1
#define MW_HOSTBOARDCONNECTION_CONNECTEDIO_PORT_SOURCE2 0
#define MW_HOSTBOARDCONNECTION_CONNECTEDIO_COMPORT_SELECT -1
#define MW_HOSTBOARDCONNECTION_CONNECTEDIO_COMPORT_SPECIFY 1
#define MW_HOSTBOARDCONNECTION_CONNECTEDIO_BAUD 0
#define MW_HOSTBOARDCONNECTION_CONNECTEDIO_BAUD_SPECIFY 
#define MW_HOSTBOARDCONNECTION_EXTERNALMODE_SERIAL_PORT 0
#define MW_HOSTBOARDCONNECTION_EXTERNALMODE_PORT_SOURCE1 1
#define MW_HOSTBOARDCONNECTION_EXTERNALMODE_PORT_SOURCE2 0
#define MW_HOSTBOARDCONNECTION_EXTERNALMODE_COMPORT_SELECT -1
#define MW_HOSTBOARDCONNECTION_EXTERNALMODE_COMPORT_SPECIFY 1
#define MW_HOSTBOARDCONNECTION_EXTERNALMODE_BAUD -1
#define MW_HOSTBOARDCONNECTION_EXTERNALMODE_BAUD_SPECIFY 
#define MW_CONNECTEDIO_CONNECTEDIOMODE 0
#define MW_CONNECTEDIO_ACTIONONOVERRUN 0
#define MW_OVERRUNDETECTION_ENABLE_OVERRUN_DETECTION 0
#define MW_OVERRUNDETECTION_DIGITAL_OUTPUT_TO_SET_ON_OVERRUN 13
#define MW_ANALOGINREFVOLTAGE_ANALOG_INPUT_REFERENCE_VOLTAGE 0.000000
#define MW_SERIAL_SERIAL0_BAUD_RATE 8
#define MW_SERIAL_SERIAL0_BAUD_SPECIFY 921600
#define MW_SERIAL_SERIAL0_CONFIG 3
#define MW_SERIAL_SERIAL2_BAUD_RATE 8
#define MW_SERIAL_SERIAL2_BAUD_SPECIFY 921600
#define MW_SERIAL_SERIAL2_CONFIG 3
#define MW_I2C_I2C0BUSSPEEDHZ 100000
#define MW_SPI_SPI_CLOCK_OUT_FREQUENCY 1
#define MW_SPI_SPI_MODE 0
#define MW_SPI_SPI_BITORDER 0
#define MW_WIFI_DISABLE_DHCP_WIFI 0
#define MW_WIFI_WIFI_IP_ADDRESS 192.168.1.20
#define MW_WIFI_WIFI_SSID yourNetwork
#define MW_WIFI_SET_WIFI_ENCRYPTION 0
#define MW_WIFI_WIFI_WEP_KEY D0D0DEADF00DABBADEAFBEADED
#define MW_WIFI_WIFI_WEP_KEY_INDEX 0
#define MW_WIFI_WIFI_WPA_PASSWORD secretPassword
#define MW_WIFI_WIFI_WPA2_USERNAME username
#define MW_WIFI_WIFI_WPA2_PASSWORD password
#define MW_THINGSPEAK_ENABLE_CUSTOMSERVER 48
#define MW_THINGSPEAK_IP_ADDRESS 184.106.153.149
#define MW_THINGSPEAK_PORT 80
#define MW_PWM_PWM_DEFAULT_FREQUENCY 1000
#define MW_BLE_PERIPHERAL_DEVICE_NAME Arduino
#define MW_BLE_PERIPHERAL_LOCAL_NAME Arduino
#define MW_BLE_ADVERTISING_INTERVAL 160
#define MW_BLE_MIN_CONNECTION_INTERVAL 6
#define MW_BLE_MAX_CONNECTION_INTERVAL 3200
#define MW_MQTT_BROKERSERVICE 0
#define MW_MQTT_BROKERADDRESS mqtt3.thingspeak.com
#define MW_MQTT_BROKERPORT 1883
#define MW_MQTT_USERNAME 
#define MW_MQTT_PASSWORD 
#define MW_MQTT_CLIENTID 
#define MW_DATAVERSION 2016.02
#define MW_DASHBOARDCODEGENINFO_ENABLECODEGEN 0
#define MW_DASHBOARDCODEGENINFO_CIRCULARGAUGE_CODEGEN 1
#define MW_DASHBOARDCODEGENINFO_CIRCULARGAUGE_BLOCKCLASS codertarget.targetHiddenBlkInsert.internal.circularGauge
#define MW_DASHBOARDCODEGENINFO_CIRCULARGAUGE_REGFCN codertarget.arduinobase.blocks.registerDashboardBlk
#define MW_DASHBOARDCODEGENINFO_CIRCULARGAUGE_VALIDATEFCN codertarget.targetHiddenBlkInsert.internal.isDashboardBlockCodegenEnabled
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

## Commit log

2022-11-24 Add rig files
    Added inventor files for rig
    [3D_model_PN_3540s-1-503l.ipt, base.ipt, bushing_loose.ipt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]
2023-01-23 Added I2C Comm
    Encoded compression rate to 7 seg 'gfedcba' hex code
2023-01-25 Built 7 Seg Driver
    Added 'abcdefg' logic
2023-03-05 Increased sample time for moving avg of rate
2023-03-10 Working on sample time and speeding up 7 seg driver
2023-03-15 Corrected overrun & increased 7seg refresh rate to 3Hz
    [MW_target_hardware_resources.h, ert_main.c]
2023-03-23 config for ESP32 Dev kit V1
    [partitions.csv]
2023-03-25 Updated GPIO and ADC pins for ESP32 Dev Kit V2 board
2023-03-27 Updated discrete sample time for 7 seg clk signal
2023-04-02 Added evaluation statistics and BLE communication for eval stats
    [partitions.csv]

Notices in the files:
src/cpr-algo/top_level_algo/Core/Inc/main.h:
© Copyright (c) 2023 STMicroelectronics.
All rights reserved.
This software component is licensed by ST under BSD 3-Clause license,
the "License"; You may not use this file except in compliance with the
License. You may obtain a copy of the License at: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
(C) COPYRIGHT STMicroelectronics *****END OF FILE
